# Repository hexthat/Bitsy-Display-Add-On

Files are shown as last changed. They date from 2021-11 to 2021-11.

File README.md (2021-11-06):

# Bitsy-Display-Add-On
OLED display for Adafruit's [ItsyBitsy](https://www.adafruit.com/?q=itsybitsy&sort=BestMatch)

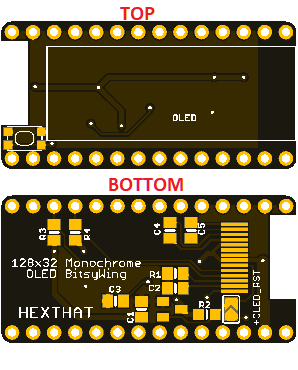
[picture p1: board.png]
Board

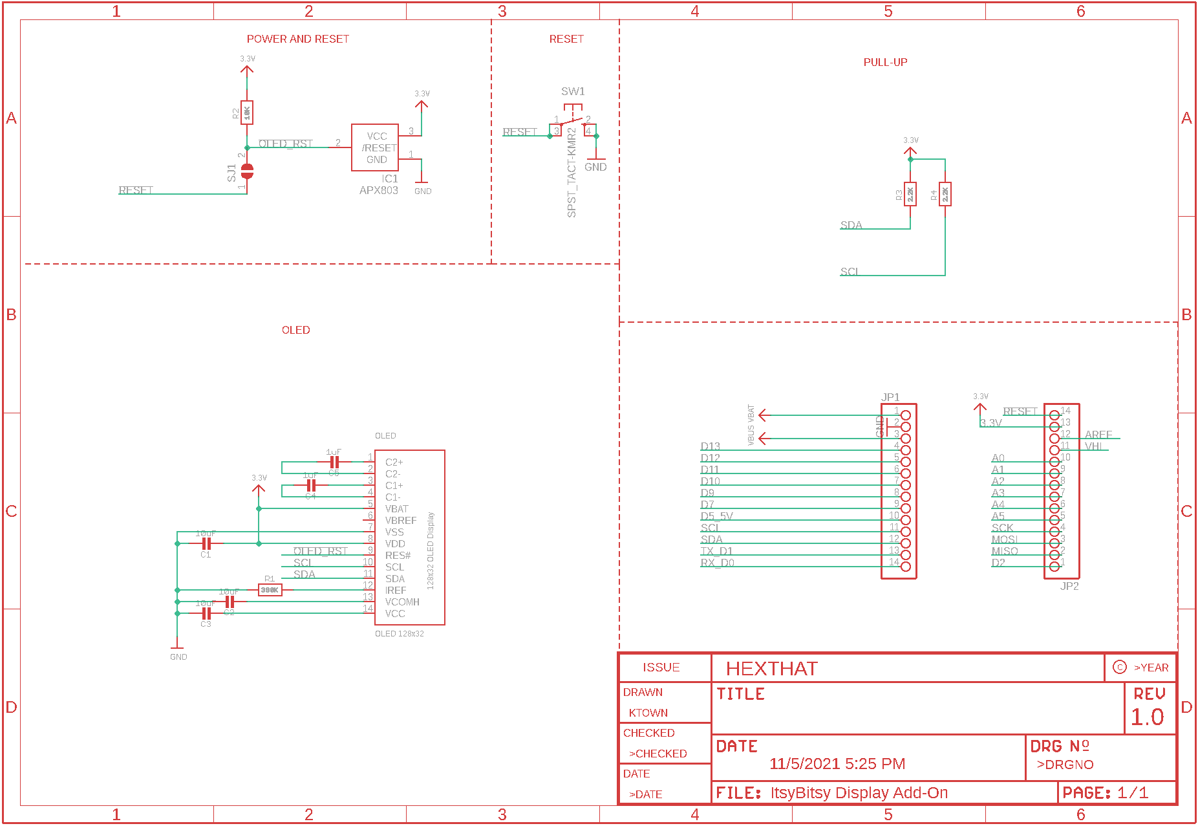
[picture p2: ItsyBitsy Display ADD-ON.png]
SCH


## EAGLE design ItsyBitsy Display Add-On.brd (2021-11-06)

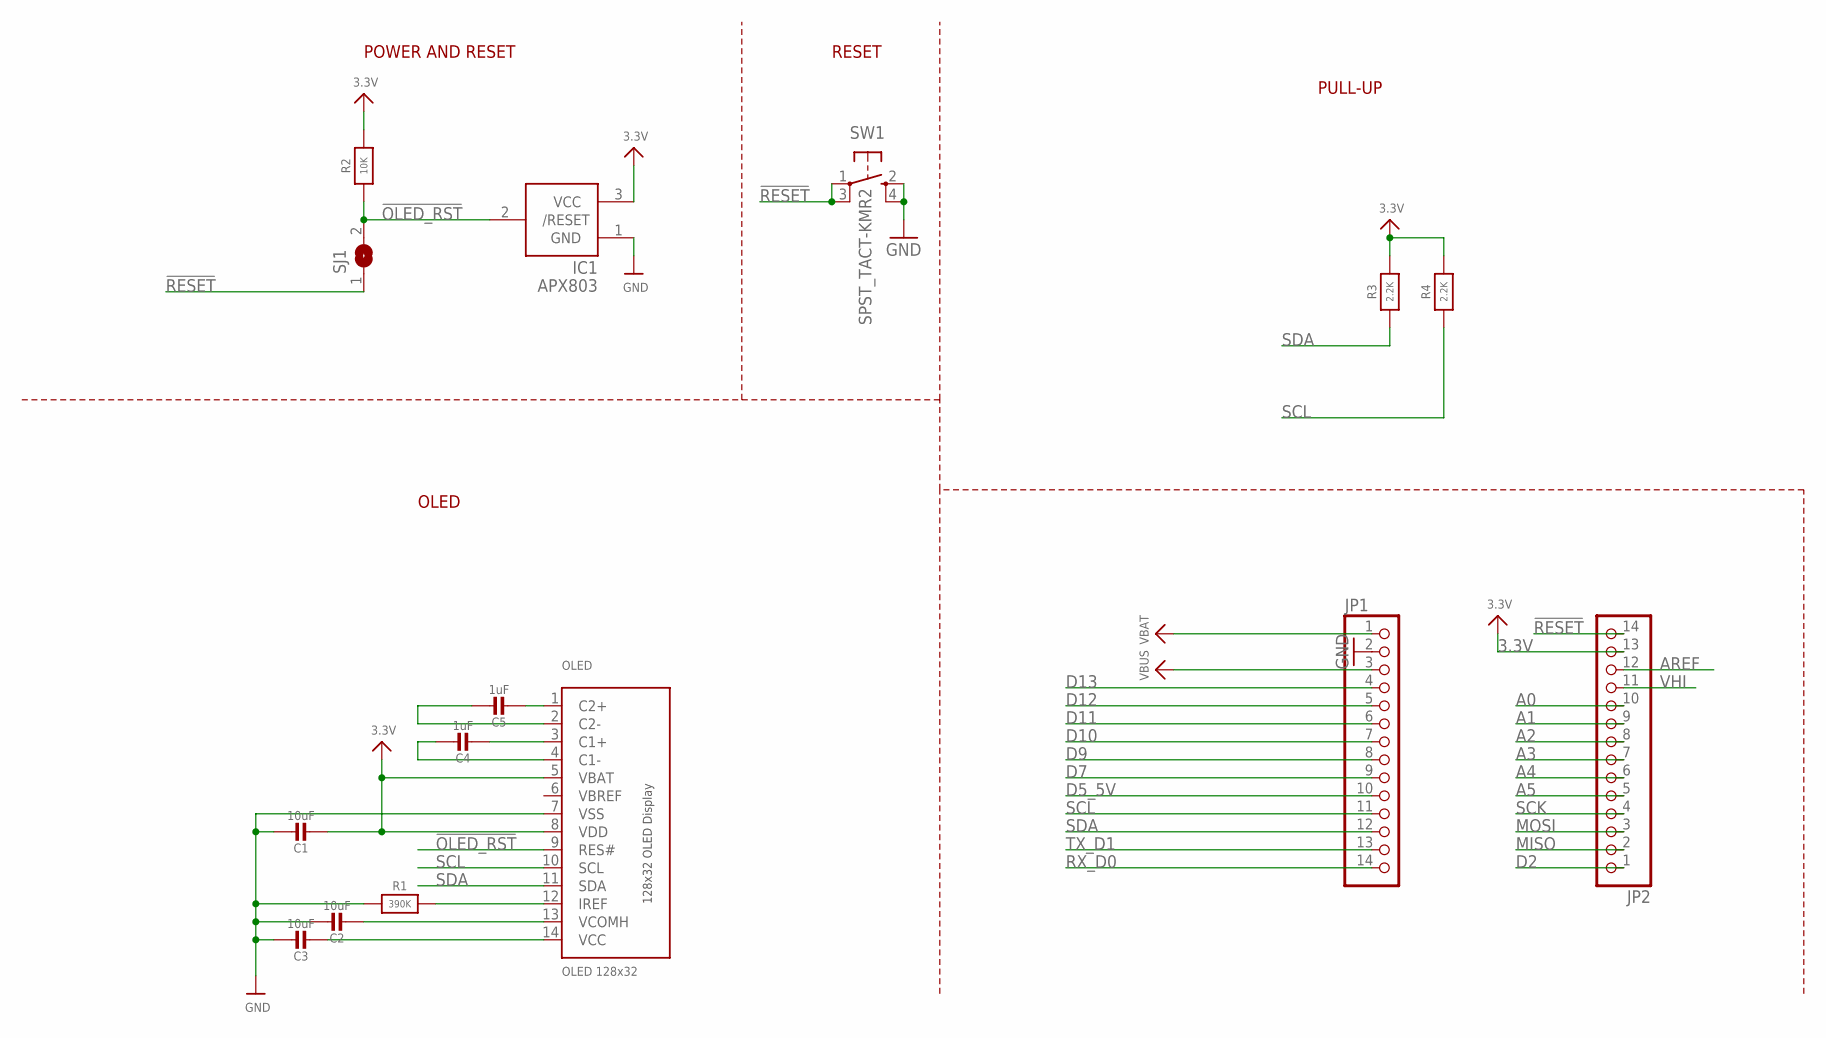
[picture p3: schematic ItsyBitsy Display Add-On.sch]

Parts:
C1, C2, C3: 10uF; 0805-NO
C4, C5: 1uF; 0805-NO
IC1: APX803; SOT23
JP1, JP2: HEADER-1X14; 1X14_ROUND70
OLED: OLED 128x32; UG-2832HSWEG02_WRAPUNDER
R1: 390K; 0805-NO
R2: 10K; _0805MP
R3, R4: 2.2K; 0805-NO
SJ1: SOLDERJUMPER; SOLDERJUMPER_ARROW_NOPASTE
SW1: SPST_TACT-KMR2; KMR2

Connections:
3.3V: C1.2, IC1.3 (VCC), JP2.13, OLED.5 (VBAT), OLED.8 (VDD), R2.2, R3.2, R4.2
!OLED_RST: IC1.2 (/RESET), OLED.9 (RES#), R2.1, SJ1.2
!RESET: JP2.14, SJ1.1, SW1.1, SW1.3 (P1)
A0: JP2.10
A1: JP2.9
A2: JP2.8
A3: JP2.7
A4: JP2.6
A5: JP2.5
AREF: JP2.12
C1N: C4.1, OLED.4 (C1-)
C1P: C4.2, OLED.3 (C1+)
C2N: C5.1, OLED.2 (C2-)
C2P: C5.2, OLED.1 (C2+)
D2: JP2.1
D5_5V: JP1.10
D7: JP1.9
D9: JP1.8
D10: JP1.7
D11: JP1.6
D12: JP1.5
D13: JP1.4
GND: C1.1, C2.1, C3.1, IC1.1 (GND), JP1.2, OLED.7 (VSS), R1.1, SW1.2 (S), SW1.4 (S1)
IREF: OLED.12 (IREF), R1.2
MISO: JP2.2
MOSI: JP2.3
RX_D0: JP1.14
SCK: JP2.4
SCL: JP1.11, OLED.10 (SCL), R4.1
SDA: JP1.12, OLED.11 (SDA), R3.1
TX_D1: JP1.13
VBAT: JP1.1
VBREF: OLED.6 (VBREF)
VBUS: JP1.3
VCC: C3.2, OLED.14 (VCC)
VCOMH: C2.2, OLED.13 (VCOMH)
VHI: JP2.11

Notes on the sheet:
POWER AND RESET
RESET
PULL-UP
OLED

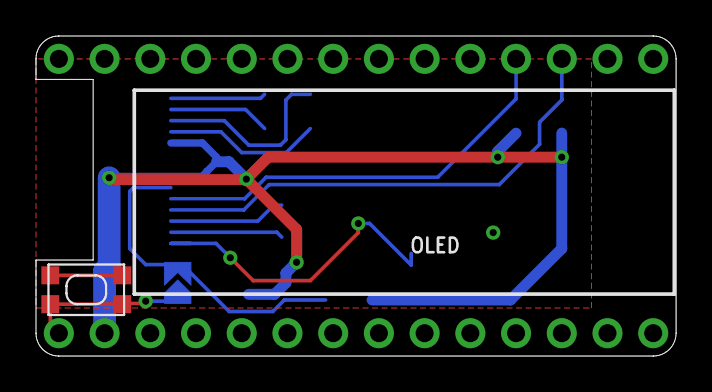
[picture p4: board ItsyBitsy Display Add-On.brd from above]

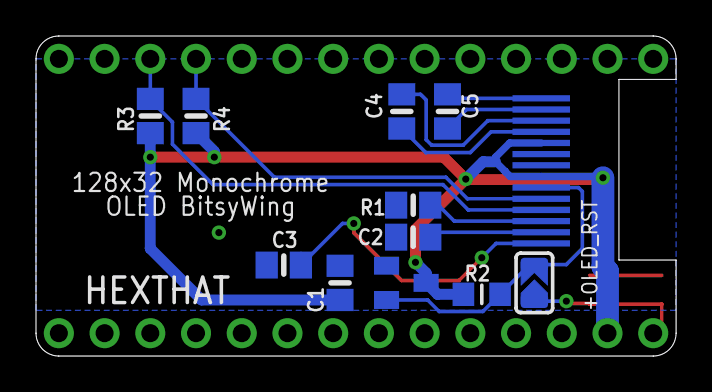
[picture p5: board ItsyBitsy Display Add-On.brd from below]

Board: 2 copper layers, 35.6 x 17.8 mm, 15 parts (11 on the bottom side), 13 nets.

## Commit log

2019-11-04 PCB
    ?
    [Bitsy Display Add-On.brd, Bitsy Display Add-On.sch]
2019-11-04 PCB Redisgned
    Resistors and Capacitors on bottom of board
    [Bitsy Display Add-On.brd, Bitsy Display Add-On.sch]
2019-11-05 PCB
    REV 1.0
    [ItsyBitsy Display Add-On.brd, ItsyBitsy Display Add-On.sch]
2019-11-05 newer version
    [Bitsy Display Add-On.brd]
2021-11-04 Small silkscreen changes
    nothing to hardware changed
    [ItsyBitsy Display Add-On.brd, ItsyBitsy Display Add-On.sch]
2021-11-06 Fixed No ground to OLED, added names
    [ItsyBitsy Display Add-On.brd, ItsyBitsy Display Add-On.sch]
2021-11-06 add info about what pad does
    [ItsyBitsy Display Add-On.brd]
2021-11-06 Moved C3, flipped jumper
    [ItsyBitsy Display Add-On.brd]
2021-11-06 >=16V added

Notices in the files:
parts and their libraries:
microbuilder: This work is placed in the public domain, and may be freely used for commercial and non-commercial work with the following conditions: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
